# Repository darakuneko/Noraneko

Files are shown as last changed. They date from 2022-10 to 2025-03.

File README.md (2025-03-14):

# Noraneko Project
Noraneko Project is an open source keyboard project.

## License
Coffee License [en](/LICENSE) / [ja](/LICENSE_JA)

☕️☕️☕️ Donation ☕️☕️☕️   
[Amazon](https://www.amazon.co.jp/hz/wishlist/ls/66VQJTRHISQT) or [Ko-fi](https://ko-fi.com/darakuneko)  

If you did sell or modify them, please let us know.

As the author, I would be very happy if you would do so.

Also if you have any questions, [please contact me](https://twitter.com/daraku__neko).

## Why is it not wired?
I want to see a variety of wires on one keyboard.

It makes for good wiring practice.

If wired, pull request kicad_pcb file under each data.

example: [wired](./noraneko42c/v1.0/pcb/wired/)  
/{keyboard}/.../pcb/wired/{username}/ 

### Wiring Engineer
[blackout](https://github.com/blackout157w) - [Noraneko52R v1.0](https://github.com/darakuneko/Noraneko/tree/main/noraneko52r/v1.0/pcb/wired/blackout)

## About Plate Data
I only have data for elecrow.

If you have created data for other stores, please make a pull request.

/{keyboard}/.../plate/{shop}/

## About Noraneko Symbol & Footprint
base on geek-rabb1t's Symbol & Footprint.

https://github.com/geek-rabb1t/keyboard_footprint

## Noraneko42C
Column Staggered Layout Keyboard.
Noraneko42C_IMG_1
Noraneko42C_IMG_2

## Noraneko52R
Row Staggered Layout Keyboard.
PB110431

## Noraneko42W
Willow Layout Keyboard.


# Noraneko42L
Lotus Layout Keyboard.


# Noraneko42GR
Grin Layout Keyboard.


# Noraneko42A
Alice Layout Keyboard.


# Noraneko42SGR
Sagittarius Layout Keyboard.


# Noraneko42UZU  
Uzu Layout Keyboard.


# Noraneko42O
Ortholinear Layout Keyboard.


# Noraneko43TS
Symmetric staggered Layout (Treadstone Layout) keyboard.


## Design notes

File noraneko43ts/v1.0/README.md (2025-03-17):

# Noraneko43TS


Noraneko43TS is 43key Symmetric staggered Layout (Treadstone Layout) keyboard.

## Parts  

Top acrylic plate --- 1 pc  
Middle acrylic plate --- 1 pc   
Main FR4 plate --- 1 pc   
Bottom acrylic plate --- 1 pc   
M2 spacer 3mm --- 6 pcs  
M2 screw 3mm --- 12 pcs  (Screw heads should be 2 mm or less）  
M2 washer --- 6 pcs  
RP2040-Zero --- 1 pc   
1N4148W --- 43 pcs  
SK6812MINI-E --- 43 pcs  
WS2812B --- 6 pcs  
MX key switch --- 43 pcs    
MX keycap    
Bumpon --- Any quantity 

## Firmware

[Firmware](https://github.com/darakuneko/Noraneko/raw/main/noraneko43ts/v1.0/firmware/noraneko43ts_vial.uf2)  
Check if the firmware can write to RP2040-Zero.  
Download the firmware.   
Connect while holding down the Boot button.  
RPI-RP2 will appear.  
Copy the downloaded firmware to RPI-RP2.  
Make sure that Noraneko43TS is connected to your PC.    
[Vial Support](https://get.vial.today/)  

## Soldering



unnamed

RP2040-Zero(SMD), Solder BSS138, Resistors, diodes, LEDs, and sockets.　  
Be careful of the direction of soldering.  
But Resistors has no polarity.

## Build


Take the bottom acrylic paper.   
Install spacers, screws, and Bumpon on bottom plate and main plate.

## Completed!!


Take the top & middle acrylic paper.  
Put on the switches and keycaps and you're done!!

## Vial 
https://get.vial.today/  
This firmware is Vial-compatible, allowing GUI-based changes to keymaps and settings.  

Web version  
https://vial.rocks/  
App version  
https://get.vial.today/download/

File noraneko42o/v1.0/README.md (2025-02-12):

# Noraneko42O  


The Noraneko42O is 42key Ortholinear Layout keyboard.  

## Parts  

Top acrylic plate --- 1 pc  
Middle acrylic plate --- 1 pc   
Main FR4 plate --- 1 pc  
Bottom1 acrylic plate --- 1 pc    
Bottom2 acrylic plate --- 1 pc  
M2 washer --- 8 pcs  
M2 spacer 3mm --- 8 pcs  
M2 screw 3.5mm --- 16 pcs (Screw heads should be 2 mm or less）  
RP2040-Zero --- 1 pc   
EC12 Rotary Encoder --- 1 pc   
1N4148W --- 42 pcs   
SK6812MINI-E --- 42 pcs  
WS2812B --- 5 pcs  
MX key switch --- 42 pcs   
MX keycap  --- 42 pcs  
Bumpon --- Any quantity 

## Firmware
    
[Firmware](https://github.com/darakuneko/Noraneko/raw/main/noraneko42o/v1.0/firmware/noraneko42o_vial.uf2)    
Check if the firmware can write to RP2040-Zero.  
Download the firmware.   
Connect while holding down the Boot button.  
RPI-RP2 will appear.  
Copy the downloaded firmware to RPI-RP2.  
Make sure that Noraneko42O is connected to your PC.   
[Vial Support](https://get.vial.today/)  

## Soldering





RP2040-Zero, Encoder, diodes, LEDs and sockets.　  
Be careful of the direction of soldering.  

## Build


Take the bottom acrylic paper.    
Install washer, spacers, screws, and Bumpon on bottom plate and main plate.    

## Completed!!


Take the top & middle acrylic paper.  
Put on the switches and keycaps and you're done!!

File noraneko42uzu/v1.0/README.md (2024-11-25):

# Noraneko42UZU  


The Noraneko42UZU is 42key UZU Layout keyboard.  

## Parts  

Top acrylic plate --- 1 pc  
Middle acrylic plate --- 1 pc   
Main FR4 plate --- 1 pc  
Bottom1 acrylic plate --- 1 pc    
Bottom2 acrylic plate --- 1 pc  
M2 spacer 3mm --- 8 pcs  
M2 screw 3mm --- 16 pcs  (Screw heads should be 2 mm or less）  
RP2040-Zero --- 1 pc   
EC12 Rotary Encoder --- 1 pc   
1N4148W --- 42 pcs   
SK6812MINI-E --- 42 pcs  
WS2812B --- 7 pcs  
MX key switch --- 42 pcs   
MX keycap  --- 42 pcs  
Bumpon --- Any quantity 

## Firmware
    
[Firmware](https://github.com/darakuneko/Noraneko/raw/main/noraneko42uzu/v1.0/firmware/noraneko42uzu_vial.uf2)    
Check if the firmware can write to RP2040-Zero.  
Download the firmware.   
Connect while holding down the Boot button.  
RPI-RP2 will appear.  
Copy the downloaded firmware to RPI-RP2.  
Make sure that Noraneko42UZU is connected to your PC.   
[Vial Support](https://get.vial.today/)  

## Soldering





RP2040-Zero, Encoder, diodes, LEDs and sockets.　  
Be careful of the direction of soldering.  

## Build


Take the bottom acrylic paper.    
Install washer, spacers, screws, and Bumpon on bottom plate and main plate.    

## Completed!!


Take the top & middle acrylic paper.  
Put on the switches and keycaps and you're done!!

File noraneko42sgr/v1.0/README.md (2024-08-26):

# Noraneko42SGR  

keyboard-layout

The Noraneko42SGR is 42key Sagittarius Layout keyboard.  

## Parts  

Top acrylic plate --- 1 pc  
Middle acrylic plate --- 1 pc   
Main FR4 plate --- 1 pc  
Bottom1 acrylic plate --- 1 pc    
Bottom2 acrylic plate --- 1 pc  
M2 spacer 3mm --- 7 pcs  
M2 screw 3.5mm --- 14 pcs  (Screw heads should be 2 mm or less）  
RP2040-Zero --- 1 pc   
1N4148W --- 42 pcs   
SK6812MINI-E --- 42 pcs  
WS2812B --- 7 pcs  
MX key switch --- 42 pcs   
MX keycap    
https://booth.pximg.net/3a4d6577-cfc5-4ca5-92b6-a2b233b974d5/i/6043317/fea123fa-a97e-4534-b815-77e4f652dba9.png   
Bumpon --- Any quantity 

## Firmware
    
[Firmware](https://github.com/darakuneko/Noraneko/raw/main/noraneko42sgr/v1.0/firmware/noraneko42sgr_vial.uf2)    
Check if the firmware can write to RP2040-Zero.  
Download the firmware.   
Connect while holding down the Boot button.  
RPI-RP2 will appear.  
Copy the downloaded firmware to RPI-RP2.  
Make sure that Noraneko42SGR is connected to your PC.   
[Vial Support](https://get.vial.today/)  

## Soldering




RP2040-Zero, diodes, LEDs and sockets.　  
Be careful of the direction of soldering.  

## Build



Take the bottom acrylic paper.    
Install washer, spacers, screws, and Bumpon on bottom plate and main plate.    

## Completed!!


Take the top & middle acrylic paper.  
Put on the switches and keycaps and you're done!!

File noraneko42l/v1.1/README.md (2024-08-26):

# Noraneko42L



Noraneko42L is 42key Lotus Layout keyboard.  

## Parts  

Top acrylic plate --- 1 pc  
Middle acrylic plate --- 1 pc   
Main FR4 plate --- 1 pc   
Bottom acrylic plate --- 1 pc   
M2 spacer 3mm --- 9 pcs  
M2 screw 3mm --- 18 pcs  (Screw heads should be 2 mm or less）  
RP2040-Zero --- 1 pc   
1N4148W --- 42 pcs  
SK6812MINI-E --- 45 pcs  
WS2812B --- 8 pcs  
MX key switch --- 42 pcs    
MX keycap   --- 42 pcs (1U)   
Bumpon --- Any quantity 

## Firmware

[Firmware](https://github.com/darakuneko/Noraneko/raw/main/noraneko42l/v1.1/firmware/noraneko42l_vial.uf2)   
Check if the firmware can write to RP2040-Zero.  
Download the firmware.   
Connect while holding down the Boot button.  
RPI-RP2 will appear.  
Copy the downloaded firmware to RPI-RP2.  
Make sure that Noraneko42L is connected to your PC.    
[Vial Support](https://get.vial.today/)  

### Feature
CAPS WORD  
https://github.com/qmk/qmk_firmware/blob/master/docs/feature_caps_word.md   

## Soldering



unnamed

RP2040-Zero(SMD), diodes, LEDs, and sockets.　  
Be careful of the direction of soldering.  
But Resistors has no polarity.

## Build


Take the bottom acrylic paper.   
Install spacers, screws, and Bumpon on bottom plate and main plate.   

If you are concerned about LED flicker caused by acrylic.  
https://twitter.com/daraku__neko/status/1652335060878753798

## Completed!!


Take the top & middle acrylic paper.  
Put on the switches and keycaps and you're done!!

## Vial 
https://get.vial.today/  
This firmware is Vial-compatible, allowing GUI-based changes to keymaps and settings.  

Web version  
https://vial.rocks/  
App version  
https://get.vial.today/download/

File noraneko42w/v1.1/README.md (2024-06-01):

# Noraneko42W

77f7c019-44f0-4f18-8f08-11a2cd835d37

Noraneko42W is 42key Willow Layout keyboard.  

## Parts  

Top acrylic plate --- 1 pc  
Middle acrylic plate --- 1 pc   
Main FR4 plate --- 1 pc   
Bottom acrylic plate --- 1 pc   
M2 spacer 3mm --- 9 pcs  
M2 screw 3mm --- 18 pcs  (Screw heads should be 2 mm or less）  
RP2040-Zero --- 1 pc   
1N4148W --- 42 pcs  
SK6812MINI-E --- 45 pcs  
WS2812B --- 12 pcs  
MX key switch --- 42 pcs    
MX keycap   --- 42 pcs (1U)   
Bumpon --- Any quantity 

## Firmware

[Firmware](https://github.com/darakuneko/Noraneko/raw/main/noraneko42w/v1.0/firmware/noraneko42w_vial.uf2)  
Check if the firmware can write to RP2040-Zero.  
Download the firmware.   
Connect while holding down the Boot button.  
RPI-RP2 will appear.  
Copy the downloaded firmware to RPI-RP2.  
Make sure that Noraneko42W is connected to your PC.    
[Vial Support](https://get.vial.today/)  

## Soldering



unnamed

RP2040-Zero(SMD), Solder BSS138, Resistors, diodes, LEDs, and sockets.　  
Be careful of the direction of soldering.  
But Resistors has no polarity.

## Build
77f7c019-44f0-4f18-8f08-11a2cd835d37

Take the bottom acrylic paper.   
Install spacers, screws, and Bumpon on bottom plate and main plate.

If you are concerned about LED flicker caused by acrylic.  
https://twitter.com/daraku__neko/status/1652335060878753798

## Completed!!


Take the top & middle acrylic paper.  
Put on the switches and keycaps and you're done!!

## Vial 
https://get.vial.today/  
This firmware is Vial-compatible, allowing GUI-based changes to keymaps and settings.  

Web version  
https://vial.rocks/  
App version  
https://get.vial.today/download/

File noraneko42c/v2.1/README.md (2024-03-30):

# Noraneko42C  
Noraneko42C_IMG_1
Noraneko42C_KeySize

The Noraneko42C is 42key column staggered keyboard.  

## Parts  

Top acrylic plate --- 1 pc  
Middle acrylic plate --- 1 pc   
Main FR4 plate --- 1 pc  
Bottom1 acrylic plate --- 1 pc    
Bottom2 acrylic plate --- 1 pc  
M2 spacer 3mm --- 7 pcs  
M2 screw 3mm --- 14 pcs  (Screw heads should be 2 mm or less）  
RP2040-Zero --- 1 pc   
1N4148W --- 42 pcs   
SK6812MINI-E --- 47 pcs  
WS2812B --- 6 pcs  
MX key switch --- 42 pcs   
MX keycap 1U --- 38 pcs  
MX keycap 1.25U --- 4 pcs  
Bumpon --- Any quantity 

## Firmware

Firmware
[v2.1](https://github.com/darakuneko/Noraneko/raw/main/noraneko42c/v2.1/firmware/noraneko42c_vial.uf2)  
Old Firmware
[v2.0](https://github.com/darakuneko/Noraneko/raw/main/noraneko42c/v2.0/firmware/noraneko42c_vial.uf2)  
Check if the firmware can write to RP2040-Zero.  
Download the firmware.   
Connect while holding down the Boot button.  
RPI-RP2 will appear.  
Copy the downloaded firmware to RPI-RP2.  
Make sure that Noraneko42C is connected to your PC.    
[Vial Support](https://get.vial.today/)  

### Feature
CAPS WORD  
https://github.com/qmk/qmk_firmware/blob/master/docs/feature_caps_word.md   

## Soldering



unnamed

RP2040-Zero(SMD),diodes, LEDs, and sockets.  
Be careful of the direction of soldering.  
But Resistors has no polarity.

## Build
Take the bottom acrylic paper.
Install spacers, screws, and Bumpon on bottom plate and main plate.
Use black masking tape to hide the LEDs.

If you are concerned about LED flicker caused by acrylic.  
https://twitter.com/daraku__neko/status/1652335060878753798

## Completed!!



Take the top & middle acrylic paper.  
Put on the switches and keycaps and you're done!!

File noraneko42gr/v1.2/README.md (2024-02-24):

# Noraneko42GR  

keyboard-layout

The Noraneko42GR is 42key GRIN Layout keyboard.  

## Parts  

Top acrylic plate --- 1 pc  
Middle acrylic plate --- 1 pc   
Main FR4 plate --- 1 pc  
Bottom1 acrylic plate --- 1 pc    
Bottom2 acrylic plate --- 1 pc  
M2 spacer 3mm or 3.5mm --- 7 pcs  
M2 washer --- 7 pcs  (Some plates require approx. 5 mm in diameter）  
M2 screw 3mm --- 14 pcs  (Screw heads should be 2 mm or less）  
RP2040-Zero --- 1 pc   
Conthrough --- 23 pin (MAC8 XB-3 height at least 3 mm)    
1N4148W --- 42 pcs   
SK6812MINI-E --- 42 pcs  
WS2812B --- 6 pcs  
MX key switch --- 42 pcs   
Stabilizers 2U --- 2 pcs    
MX keycap    
https://booth.pximg.net/3a4d6577-cfc5-4ca5-92b6-a2b233b974d5/i/4311339/b372f2f2-1520-4431-a8cc-eac1ec2c977d.png   
Bumpon --- Any quantity 

## Firmware
    
[Firmware](https://github.com/darakuneko/Noraneko/raw/main/noraneko42gr/v1.1/firmware/noraneko42gr_vial.uf2)    
Check if the firmware can write to RP2040-Zero.  
Download the firmware. (Firmware prior to v1.1 is on a separate pagel)     
Connect while holding down the Boot button.  
RPI-RP2 will appear.  
Copy the downloaded firmware to RPI-RP2.  
Make sure that Noraneko42GR is connected to your PC.   
[Vial Support](https://get.vial.today/)  

## Soldering






RP2040-Zero, diodes, LEDs, and sockets.　  
Be careful of the direction of soldering.  
But Resistors has no polarity.

## Build
Take the bottom acrylic paper.    
Install spacers, screws, washer and Bumpon on bottom plate and main plate.    


## Completed!!


Take the top & middle acrylic paper.  
Put on the switches and keycaps and you're done!!

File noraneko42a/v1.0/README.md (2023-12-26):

# Noraneko42A  

keyboard-layout

The Noraneko42A is 42key Alice Layout keyboard.  

## Parts  

Top acrylic plate --- 1 pc  
Middle acrylic plate --- 1 pc   
Main FR4 plate --- 1 pc  
Bottom1 acrylic plate --- 1 pc    
Bottom2 acrylic plate --- 1 pc  
M2 washer --- 7 pcs  
M2 spacer 3mm --- 7 pcs  
M2 screw 3.5mm --- 14 pcs  (Screw heads should be 2 mm or less）  
RP2040-Zero --- 1 pc   
1N4148W --- 42 pcs   
SK6812MINI-E --- 42 pcs  
WS2812B --- 8 pcs  
MX key switch --- 42 pcs   
Stabilizers 2U --- 2 pcs    
MX keycap    
https://booth.pximg.net/3a4d6577-cfc5-4ca5-92b6-a2b233b974d5/i/5374158/5d14389b-c7e3-49fb-a8d4-9945c7a1167a.png   
Bumpon --- Any quantity 

## Firmware
    
[Firmware](https://github.com/darakuneko/Noraneko/raw/main/noraneko42a/v1.0/firmware/noraneko42a_vial.uf2)    
Check if the firmware can write to RP2040-Zero.  
Download the firmware.   
Connect while holding down the Boot button.  
RPI-RP2 will appear.  
Copy the downloaded firmware to RPI-RP2.  
Make sure that Noraneko42A is connected to your PC.   
[Vial Support](https://get.vial.today/)  

## Soldering




RP2040-Zero, diodes, LEDs and sockets.　  
Be careful of the direction of soldering.  

## Build


Take the bottom acrylic paper.    
Install washer, spacers, screws, and Bumpon on bottom plate and main plate.    

## Completed!!


Take the top & middle acrylic paper.  
Put on the switches and keycaps and you're done!!

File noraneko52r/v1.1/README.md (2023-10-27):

# Noraneko52R  
PB110430


Noraneko52R is 52key row staggered keyboard.  

## Parts  

Top acrylic plate --- 1 pc  
Middle acrylic plate --- 1 pc   
Main FR4 plate --- 1 pc   
Bottom1 acrylic plate --- 1 pc   
Bottom2 acrylic plate --- 1 pc   
M2 spacer 3mm --- 7 pcs  
M2 screw 3mm --- 14 pcs  (Screw heads should be 2 mm or less）  
RP2040-Zero --- 1 pc  
Pin header 9pin --- 2 pcs   
Pin header 5pin --- 1 pc  
1N4148W --- 52 pcs  
SK6812MINI-E --- 52 pcs  
WS2812B --- 13 pcs  
BSS138 --- 1 pc  
Resistor 1K Ohm 1/4 Watt PTH --- 2 pcs   
If it does not glow, change the type of resistor. ([reference](https://25keys.com/2022/05/28/rp2040_sk6812mini/))   

MX key switch --- 52 pcs  
Stabilizers 2U --- 2 pcs (GMK Screw-in Stabilizers are recommended)   
MX keycap    
https://booth.pximg.net/3a4d6577-cfc5-4ca5-92b6-a2b233b974d5/i/4311339/b372f2f2-1520-4431-a8cc-eac1ec2c977d.png   
Bumpon --- Any quantity 

## Firmware

[Firmware](https://github.com/darakuneko/Noraneko/raw/main/noraneko52r/v1.0/firmware/noraneko52r_vial.uf2)  
Check if the firmware can write to RP2040-Zero.  
Download the firmware.   
Connect while holding down the Boot button.  
RPI-RP2 will appear.  
Copy the downloaded firmware to RPI-RP2.  
Make sure that Noraneko52R is connected to your PC.    
[Vial Support](https://get.vial.today/)  

### Feature
CAPS WORD  
https://github.com/qmk/qmk_firmware/blob/master/docs/feature_caps_word.md   

## Soldering






Solder BSS138, Resistors, diodes, LEDs, and sockets.　  
Be careful of the direction of soldering.  
But Resistors has no polarity.

RP2040-Zero

For direct soldering using pin headers, see [here](https://kbdbuild.vercel.app/blog/yamada_pro_micro).  
This is doing this with ProMicro, but it is the same with RP2040-Zero.   
Be careful of the direction of soldering.  

## Build


the screw part's height of the stabilizer should be 3mm or less.   
GMK Screw-in Stabilizers are recommended.   




Take the bottom1 & bottom2 acrylic paper.   
Install spacers, screws, and Bumpon on bottom plate and main plate.

If you are concerned about LED flicker caused by acrylic.  
https://twitter.com/daraku__neko/status/1652335060878753798

## Completed!!
PB110430

Take the top & middle acrylic paper.  
Put on the switches and keycaps and you're done!!

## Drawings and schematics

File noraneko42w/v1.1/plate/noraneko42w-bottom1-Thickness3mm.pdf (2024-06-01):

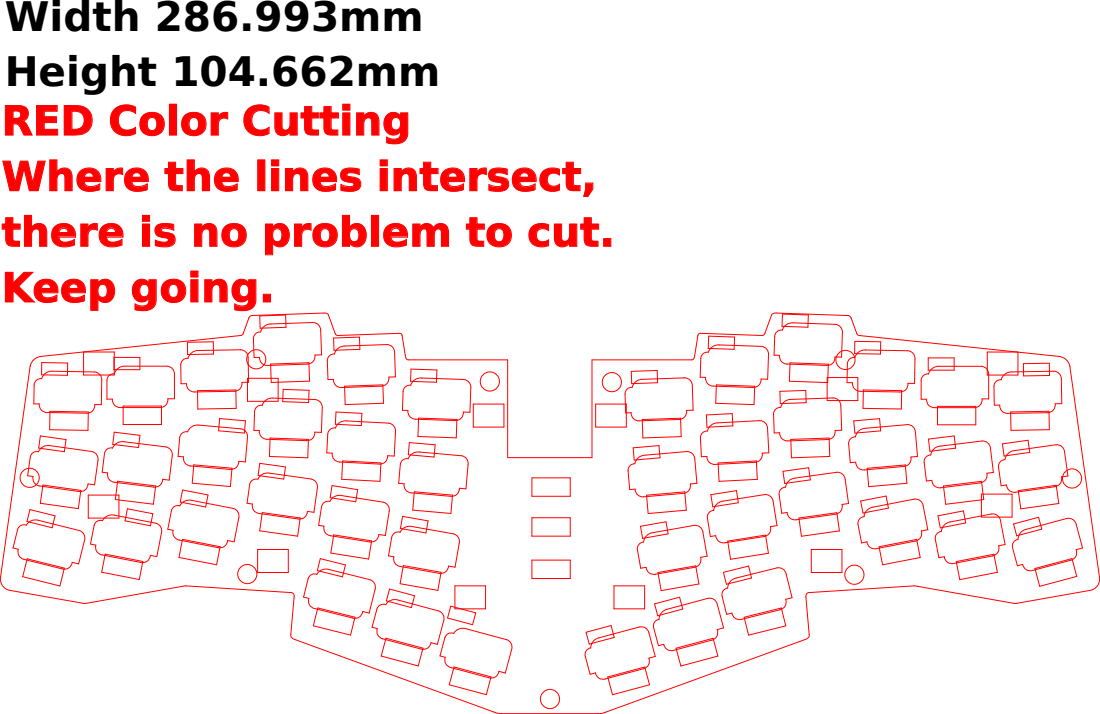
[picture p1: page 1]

Width 286.993mm
Height 104.662mm
RED Color Cutting
Where the lines intersect,
there is no problem to cut.
Keep going.

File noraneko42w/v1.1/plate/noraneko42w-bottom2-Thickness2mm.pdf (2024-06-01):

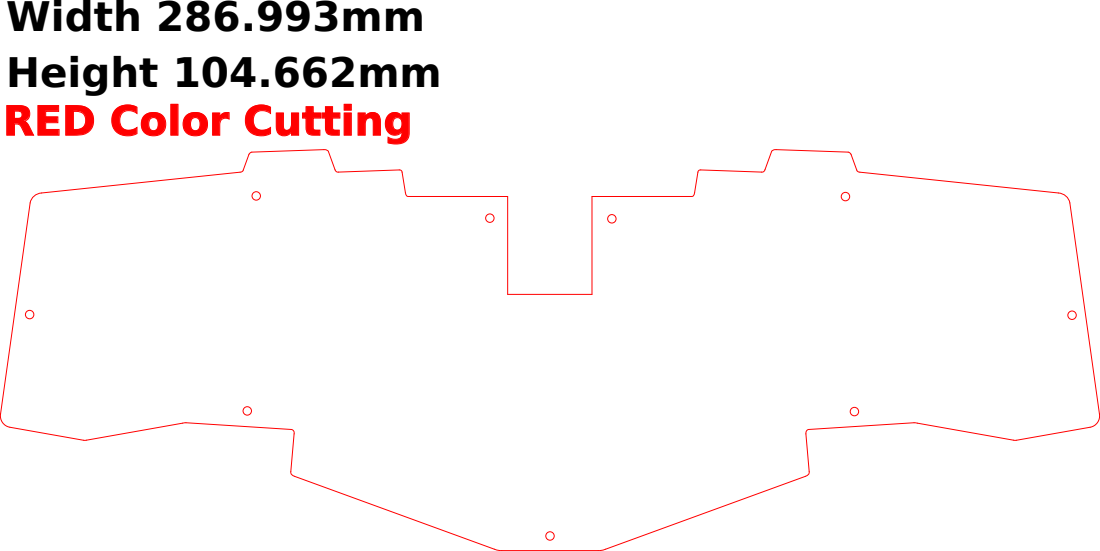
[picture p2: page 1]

Width 286.993mm
Height 104.662mm
RED Color Cutting

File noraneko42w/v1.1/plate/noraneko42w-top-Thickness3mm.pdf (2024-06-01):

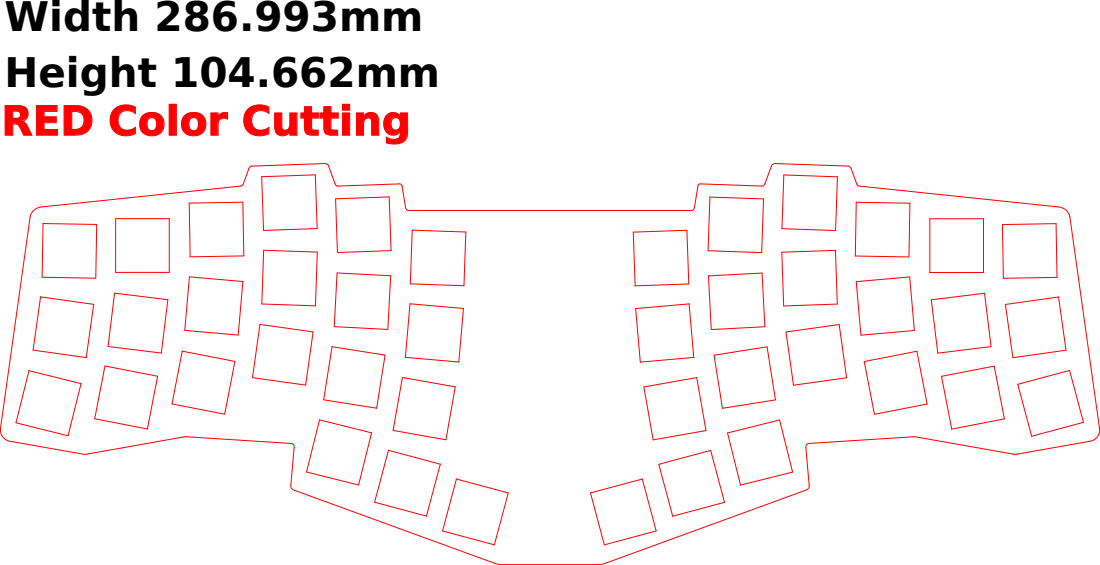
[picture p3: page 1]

Width 286.993mm
Height 104.662mm
RED Color Cutting

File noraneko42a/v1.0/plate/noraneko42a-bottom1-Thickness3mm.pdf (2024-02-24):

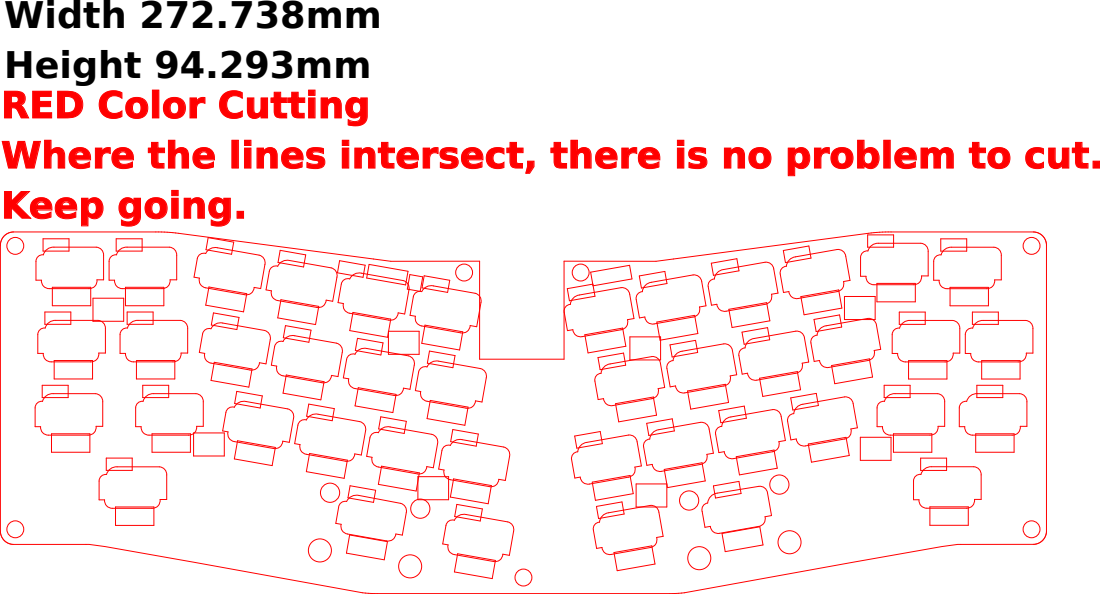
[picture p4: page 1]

Width 272.738mm
Height 94.293mm
RED Color Cutting
Where the lines intersect, there is no problem to cut.
Keep going.

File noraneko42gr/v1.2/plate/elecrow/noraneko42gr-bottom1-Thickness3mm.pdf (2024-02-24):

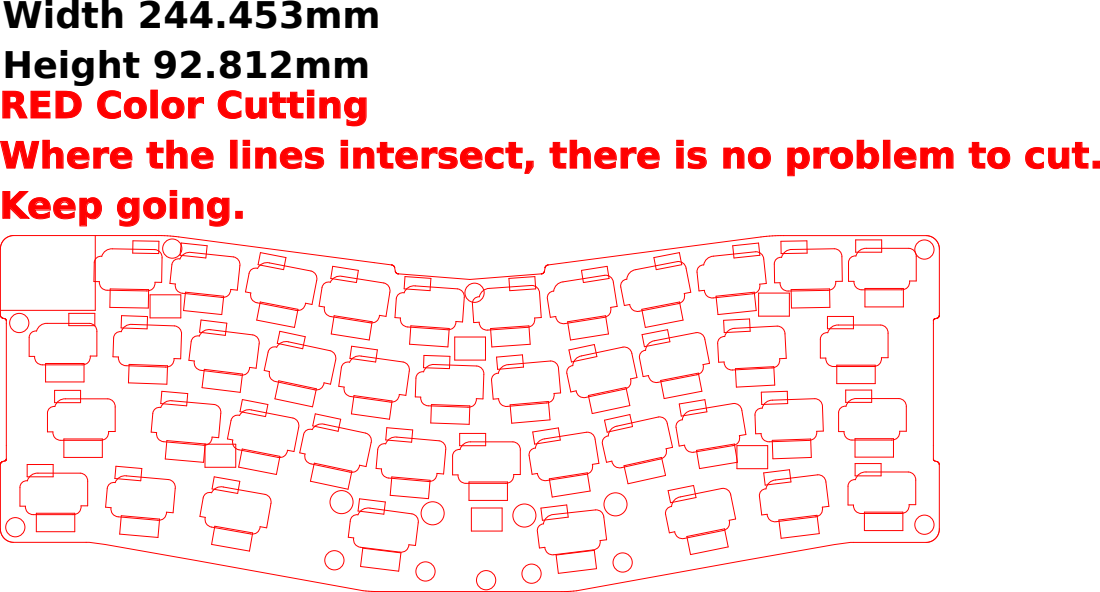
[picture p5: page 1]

Width 244.453mm
Height 92.812mm
RED Color Cutting
Where the lines intersect, there is no problem to cut.
Keep going.

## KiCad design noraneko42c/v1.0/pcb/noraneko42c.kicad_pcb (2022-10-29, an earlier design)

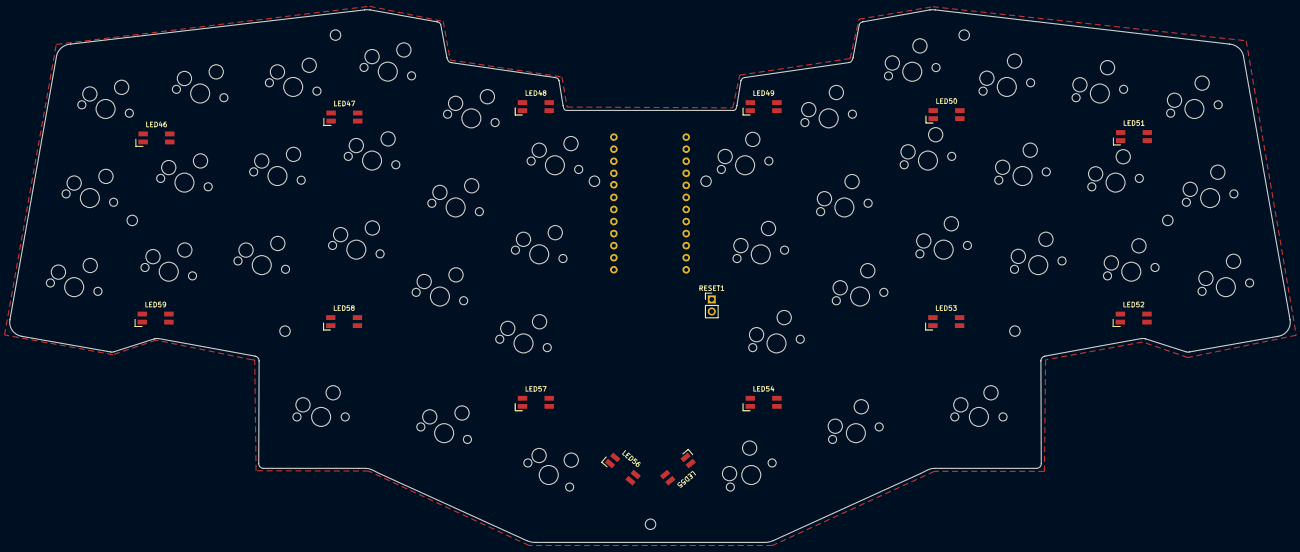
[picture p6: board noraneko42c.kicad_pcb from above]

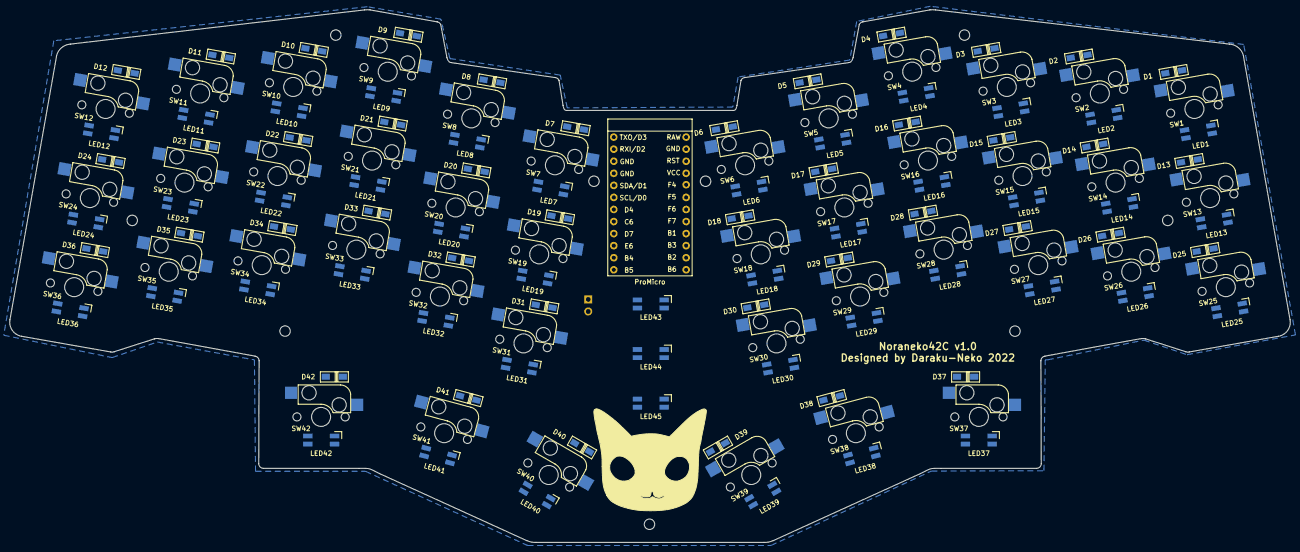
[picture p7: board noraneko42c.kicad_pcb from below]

Board: 2 copper layers, 269.7 x 112.2 mm, 145 parts (88 on the bottom side), 120 nets, no tracks yet.

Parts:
D1, D2, D3, D4, D5, D6, D7, D8, D9, D10, D11, D12, D13, D14, D15, D16, D17, D18, D19, D20, D21, D22, D23, D24, D25, D26, D27, D28, D29, D30, D31, D32, D33, D34, D35, D36, D37, D38, D39, D40, D41, D42: D; 1N4148W
LED1, LED2, LED3, LED4, LED5, LED6, LED7, LED8, LED9, LED10, LED11, LED12, LED13, LED14, LED15, LED16, LED17, LED18, LED19, LED20, LED21, LED22, LED23, LED24, LED25, LED26, LED27, LED28, LED29, LED30, LED31, LED32, LED33, LED34, LED35, LED36, LED37, LED38, LED39, LED40, LED41, LED42, LED43, LED44, LED45, LED46, LED47, LED48, LED49, LED50, LED51, LED52, LED53, LED54, LED55, LED56, LED57, LED58, LED59: SK6812MINI-E
RESET1: SW_Push; PinHeader_1x02_P2.54mm_Vertical
SW1, SW2, SW3, SW4, SW5, SW6, SW7, SW8, SW9, SW10, SW11, SW12, SW13, SW14, SW15, SW16, SW17, SW18, SW19, SW20, SW21, SW22, SW23, SW24, SW25, SW26, SW27, SW28, SW29, SW30, SW31, SW32, SW33, SW34, SW35, SW36, SW37, SW38, SW39, SW40, SW41, SW42: SW_Push; MX_Socket
U1: ProMicro; Pro_Micro

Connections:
COL0: SW1.1, SW13.1, SW25.1, SW37.1, U1.20 (A3/F4)
COL1: SW2.1, SW14.1, SW26.1, SW38.1, U1.19 (A2/F5)
COL2: SW3.1, SW15.1, SW27.1, SW39.1, U1.18 (A1/F6)
COL3: SW4.1, SW16.1, SW28.1, SW40.1, U1.17 (A0/F7)
COL4: SW5.1, SW17.1, SW29.1, SW41.1, U1.16 (B1)
COL5: SW6.1, SW18.1, SW30.1, SW42.1, U1.15 (B3)
COL6: SW7.1, SW19.1, SW31.1, U1.14 (B2)
COL7: SW8.1, SW20.1, SW32.1, U1.13 (B6)
COL8: SW9.1, SW21.1, SW33.1, U1.12 (B5)
COL9: SW10.1, SW22.1, SW34.1, U1.11 (B4)
COL10: SW11.1, SW23.1, SW35.1, U1.10 (E6)
COL11: SW12.1, SW24.1, SW36.1, U1.9 (D7)
GND: LED1.3 (VSS), LED2.3 (VSS), LED3.3 (VSS), LED4.3 (VSS), LED5.3 (VSS), LED6.3 (VSS), LED7.3 (VSS), LED8.3 (VSS), LED9.3 (VSS), LED10.3 (VSS), LED11.3 (VSS), LED12.3 (VSS), LED13.3 (VSS), LED14.3 (VSS), LED15.3 (VSS), LED16.3 (VSS), LED17.3 (VSS), LED18.3 (VSS), LED19.3 (VSS), LED20.3 (VSS), LED21.3 (VSS), LED22.3 (VSS), LED23.3 (VSS), LED24.3 (VSS), LED25.3 (VSS), LED26.3 (VSS), LED27.3 (VSS), LED28.3 (VSS), LED29.3 (VSS), LED30.3 (VSS), LED31.3 (VSS), LED32.3 (VSS), LED33.3 (VSS), LED34.3 (VSS), LED35.3 (VSS), LED36.3 (VSS), LED37.3 (VSS), LED38.3 (VSS), LED39.3 (VSS), LED40.3 (VSS), LED41.3 (VSS), LED42.3 (VSS), LED43.3 (VSS), LED44.3 (VSS), LED45.3 (VSS), LED46.3 (VSS), LED47.3 (VSS), LED48.3 (VSS), LED49.3 (VSS), LED50.3 (VSS), LED51.3 (VSS), LED52.3 (VSS), LED53.3 (VSS), LED54.3 (VSS), LED55.3 (VSS), LED56.3 (VSS), LED57.3 (VSS), LED58.3 (VSS), LED59.3 (VSS), RESET1.2, U1.3 (GND), U1.4 (GND), U1.23 (GND)
LED: LED1.4 (DIN), U1.1 (TX0/D3)
unnamed: D1.2 (A), SW1.2
unnamed: D2.2 (A), SW2.2
unnamed: D3.2 (A), SW3.2
unnamed: D4.2 (A), SW4.2
unnamed: D5.2 (A), SW5.2
unnamed: D6.2 (A), SW6.2
unnamed: D7.2 (A), SW7.2
unnamed: D8.2 (A), SW8.2
unnamed: D9.2 (A), SW9.2
unnamed: D10.2 (A), SW10.2
unnamed: D11.2 (A), SW11.2
unnamed: D12.2 (A), SW12.2
unnamed: D13.2 (A), SW13.2
unnamed: D14.2 (A), SW14.2
unnamed: D15.2 (A), SW15.2
unnamed: D16.2 (A), SW16.2
unnamed: D17.2 (A), SW17.2
unnamed: D18.2 (A), SW18.2
unnamed: D19.2 (A), SW19.2
unnamed: D20.2 (A), SW20.2
unnamed: D21.2 (A), SW21.2
unnamed: D22.2 (A), SW22.2
unnamed: D23.2 (A), SW23.2
unnamed: D24.2 (A), SW24.2
unnamed: D25.2 (A), SW25.2
unnamed: D26.2 (A), SW26.2
unnamed: D27.2 (A), SW27.2
unnamed: D28.2 (A), SW28.2
unnamed: D29.2 (A), SW29.2
unnamed: D30.2 (A), SW30.2
unnamed: D31.2 (A), SW31.2
unnamed: D32.2 (A), SW32.2
unnamed: D33.2 (A), SW33.2
unnamed: D34.2 (A), SW34.2
unnamed: D35.2 (A), SW35.2
unnamed: D36.2 (A), SW36.2
unnamed: D37.2 (A), SW37.2
unnamed: D38.2 (A), SW38.2
unnamed: D39.2 (A), SW39.2
unnamed: D40.2 (A), SW40.2
unnamed: D41.2 (A), SW41.2
unnamed: D42.2 (A), SW42.2
unnamed: LED1.2 (DOUT), LED2.4 (DIN)
unnamed: LED2.2 (DOUT), LED3.4 (DIN)
unnamed: LED3.2 (DOUT), LED4.4 (DIN)
unnamed: LED4.2 (DOUT), LED5.4 (DIN)
unnamed: LED5.2 (DOUT), LED6.4 (DIN)
unnamed: LED6.2 (DOUT), LED7.4 (DIN)
unnamed: LED7.2 (DOUT), LED8.4 (DIN)
unnamed: LED8.2 (DOUT), LED9.4 (DIN)
unnamed: LED10.2 (DOUT), LED11.4 (DIN)
unnamed: LED9.2 (DOUT), LED10.4 (DIN)
unnamed: LED11.2 (DOUT), LED12.4 (DIN)
unnamed: LED12.2 (DOUT), LED13.4 (DIN)
unnamed: LED13.2 (DOUT), LED14.4 (DIN)
unnamed: LED14.2 (DOUT), LED15.4 (DIN)
unnamed: LED15.2 (DOUT), LED16.4 (DIN)
unnamed: LED16.2 (DOUT), LED17.4 (DIN)
unnamed: LED17.2 (DOUT), LED18.4 (DIN)
unnamed: LED18.2 (DOUT), LED19.4 (DIN)
unnamed: LED19.2 (DOUT), LED20.4 (DIN)
unnamed: LED20.2 (DOUT), LED21.4 (DIN)
unnamed: LED21.2 (DOUT), LED22.4 (DIN)
unnamed: LED22.2 (DOUT), LED23.4 (DIN)
unnamed: LED23.2 (DOUT), LED24.4 (DIN)
unnamed: LED24.2 (DOUT), LED25.4 (DIN)
unnamed: LED25.2 (DOUT), LED26.4 (DIN)
unnamed: LED26.2 (DOUT), LED27.4 (DIN)
unnamed: LED27.2 (DOUT), LED28.4 (DIN)
unnamed: LED28.2 (DOUT), LED29.4 (DIN)
unnamed: LED29.2 (DOUT), LED30.4 (DIN)
unnamed: LED30.2 (DOUT), LED31.4 (DIN)
unnamed: LED31.2 (DOUT), LED32.4 (DIN)
unnamed: LED32.2 (DOUT), LED33.4 (DIN)
unnamed: LED33.2 (DOUT), LED34.4 (DIN)
unnamed: LED34.2 (DOUT), LED35.4 (DIN)
unnamed: LED35.2 (DOUT), LED36.4 (DIN)
unnamed: LED36.2 (DOUT), LED37.4 (DIN)
unnamed: LED37.2 (DOUT), LED38.4 (DIN)
unnamed: LED38.2 (DOUT), LED39.4 (DIN)
unnamed: LED39.2 (DOUT), LED40.4 (DIN)
unnamed: LED40.2 (DOUT), LED41.4 (DIN)
unnamed: LED41.2 (DOUT), LED42.4 (DIN)
unnamed: LED42.2 (DOUT), LED43.4 (DIN)
unnamed: LED43.2 (DOUT), LED44.4 (DIN)
unnamed: LED44.2 (DOUT), LED45.4 (DIN)
unnamed: LED45.2 (DOUT), LED46.4 (DIN)
unnamed: LED46.2 (DOUT), LED47.4 (DIN)
unnamed: LED47.2 (DOUT), LED48.4 (DIN)
unnamed: LED48.2 (DOUT), LED49.4 (DIN)
unnamed: LED49.2 (DOUT), LED50.4 (DIN)
unnamed: LED50.2 (DOUT), LED51.4 (DIN)
unnamed: LED51.2 (DOUT), LED52.4 (DIN)
unnamed: LED52.2 (DOUT), LED53.4 (DIN)
unnamed: LED53.2 (DOUT), LED54.4 (DIN)
unnamed: LED54.2 (DOUT), LED55.4 (DIN)
unnamed: LED55.2 (DOUT), LED56.4 (DIN)
unnamed: LED56.2 (DOUT), LED57.4 (DIN)
unnamed: LED57.2 (DOUT), LED58.4 (DIN)
unnamed: LED58.2 (DOUT), LED59.4 (DIN)
ROW0: D1.1 (K), D2.1 (K), D3.1 (K), D4.1 (K), D5.1 (K), D6.1 (K), D7.1 (K), D8.1 (K), D9.1 (K), D10.1 (K), D11.1 (K), D12.1 (K), U1.8 (C6)
ROW1: D13.1 (K), D14.1 (K), D15.1 (K), D16.1 (K), D17.1 (K), D18.1 (K), D19.1 (K), D20.1 (K), D21.1 (K), D22.1 (K), D23.1 (K), D24.1 (K), U1.7 (D4)
ROW2: D25.1 (K), D26.1 (K), D27.1 (K), D28.1 (K), D29.1 (K), D30.1 (K), D31.1 (K), D32.1 (K), D33.1 (K), D34.1 (K), D35.1 (K), D36.1 (K), U1.6 (SCL/D0)
ROW3: D37.1 (K), D38.1 (K), D39.1 (K), D40.1 (K), D41.1 (K), D42.1 (K), U1.5 (SDA/D1)
VCC: LED1.1 (VDD), LED2.1 (VDD), LED3.1 (VDD), LED4.1 (VDD), LED5.1 (VDD), LED6.1 (VDD), LED7.1 (VDD), LED8.1 (VDD), LED9.1 (VDD), LED10.1 (VDD), LED11.1 (VDD), LED12.1 (VDD), LED13.1 (VDD), LED14.1 (VDD), LED15.1 (VDD), LED16.1 (VDD), LED17.1 (VDD), LED18.1 (VDD), LED19.1 (VDD), LED20.1 (VDD), LED21.1 (VDD), LED22.1 (VDD), LED23.1 (VDD), LED24.1 (VDD), LED25.1 (VDD), LED26.1 (VDD), LED27.1 (VDD), LED28.1 (VDD), LED29.1 (VDD), LED30.1 (VDD), LED31.1 (VDD), LED32.1 (VDD), LED33.1 (VDD), LED34.1 (VDD), LED35.1 (VDD), LED36.1 (VDD), LED37.1 (VDD), LED38.1 (VDD), LED39.1 (VDD), LED40.1 (VDD), LED41.1 (VDD), LED42.1 (VDD), LED43.1 (VDD), LED44.1 (VDD), LED45.1 (VDD), LED46.1 (VDD), LED47.1 (VDD), LED48.1 (VDD), LED49.1 (VDD), LED50.1 (VDD), LED51.1 (VDD), LED52.1 (VDD), LED53.1 (VDD), LED54.1 (VDD), LED55.1 (VDD), LED56.1 (VDD), LED57.1 (VDD), LED58.1 (VDD), LED59.1 (VDD), U1.21 (VCC)
reset: RESET1.1, U1.22 (RST)

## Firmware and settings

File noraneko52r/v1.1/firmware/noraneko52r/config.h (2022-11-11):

/*
Copyright 2022 daraku_neko
This program is free software: you can redistribute it and/or modify
it under the terms of the GNU General Public License as published by
the Free Software Foundation, either version 2 of the License, or
(at your option) any later version.
This program is distributed in the hope that it will be useful,
but WITHOUT ANY WARRANTY; without even the implied warranty of
MERCHANTABILITY or FITNESS FOR A PARTICULAR PURPOSE.  See the
GNU General Public License for more details.
You should have received a copy of the GNU General Public License
along with this program.  If not, see <http://www.gnu.org/licenses/>.
*/

#pragma once

#include "config_common.h"

/* USB Device descriptor parameter */
#define VENDOR_ID    0xFEED
#define PRODUCT_ID   0x1527
#define DEVICE_VER   0x0001
#define MANUFACTURER Daraku-Neko
#define PRODUCT      Noraneko52R

#define RGB_DI_PIN GP0
#define RGBLED_NUM 65
#define DRIVER_LED_TOTAL 65
#define RGB_MATRIX_MAXIMUM_BRIGHTNESS 200
#define RGB_MATRIX_CENTER { 112, 32 }
#define RGB_DISABLE_TIMEOUT 120000
#define RGB_DISABLE_WHEN_USB_SUSPENDED true
#define RGB_MATRIX_HUE_STEP 4
#define RGB_MATRIX_SAT_STEP 4
#define RGB_MATRIX_VAL_STEP 4
#define RGB_MATRIX_SPD_STEP 4
#define RGB_MATRIX_KEYPRESSES
#define RGB_MATRIX_FRAMEBUFFER_EFFECTS
#define ENABLE_RGB_MATRIX_ALPHAS_MODS
#define ENABLE_RGB_MATRIX_GRADIENT_UP_DOWN
#define ENABLE_RGB_MATRIX_GRADIENT_LEFT_RIGHT
#define ENABLE_RGB_MATRIX_BREATHING
#define ENABLE_RGB_MATRIX_BAND_SAT
#define ENABLE_RGB_MATRIX_BAND_VAL
#define ENABLE_RGB_MATRIX_BAND_PINWHEEL_SAT
#define ENABLE_RGB_MATRIX_BAND_PINWHEEL_VAL
#define ENABLE_RGB_MATRIX_BAND_SPIRAL_SAT
#define ENABLE_RGB_MATRIX_BAND_SPIRAL_VAL
#define ENABLE_RGB_MATRIX_CYCLE_ALL
#define ENABLE_RGB_MATRIX_CYCLE_LEFT_RIGHT
#define ENABLE_RGB_MATRIX_CYCLE_UP_DOWN
#define ENABLE_RGB_MATRIX_RAINBOW_MOVING_CHEVRON
#define ENABLE_RGB_MATRIX_CYCLE_OUT_IN
#define ENABLE_RGB_MATRIX_CYCLE_OUT_IN_DUAL
#define ENABLE_RGB_MATRIX_CYCLE_PINWHEEL
#define ENABLE_RGB_MATRIX_CYCLE_SPIRAL
#define ENABLE_RGB_MATRIX_DUAL_BEACON
#define ENABLE_RGB_MATRIX_RAINBOW_BEACON
#define ENABLE_RGB_MATRIX_RAINBOW_PINWHEELS
#define ENABLE_RGB_MATRIX_RAINDROPS
#define ENABLE_RGB_MATRIX_JELLYBEAN_RAINDROPS
#define ENABLE_RGB_MATRIX_HUE_BREATHING
#define ENABLE_RGB_MATRIX_HUE_PENDULUM
#define ENABLE_RGB_MATRIX_HUE_WAVE
#define ENABLE_RGB_MATRIX_PIXEL_FRACTAL
#define ENABLE_RGB_MATRIX_PIXEL_FLOW
#define ENABLE_RGB_MATRIX_PIXEL_RAIN
#define ENABLE_RGB_MATRIX_TYPING_HEATMAP
#define ENABLE_RGB_MATRIX_DIGITAL_RAIN
#define ENABLE_RGB_MATRIX_SOLID_REACTIVE_SIMPLE
#define ENABLE_RGB_MATRIX_SOLID_REACTIVE
#define ENABLE_RGB_MATRIX_SOLID_REACTIVE_WIDE
#define ENABLE_RGB_MATRIX_SOLID_REACTIVE_MULTIWIDE
#define ENABLE_RGB_MATRIX_SOLID_REACTIVE_CROSS
#define ENABLE_RGB_MATRIX_SOLID_REACTIVE_MULTICROSS
#define ENABLE_RGB_MATRIX_SOLID_REACTIVE_NEXUS
#define ENABLE_RGB_MATRIX_SOLID_REACTIVE_MULTINEXUS
#define ENABLE_RGB_MATRIX_SPLASH
#define ENABLE_RGB_MATRIX_MULTISPLASH
#define ENABLE_RGB_MATRIX_SOLID_SPLASH
#define ENABLE_RGB_MATRIX_SOLID_MULTISPLASH
#define RGB_MATRIX_STARTUP_MODE RGB_MATRIX_CYCLE_UP_DOWN

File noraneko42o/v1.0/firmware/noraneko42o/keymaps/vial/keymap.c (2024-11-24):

/* SPDX-License-Identifier: GPL-2.0-or-later */

#include QMK_KEYBOARD_H

const uint16_t PROGMEM keymaps[][MATRIX_ROWS][MATRIX_COLS] = {
	[0] = LAYOUT(
		KC_Q, KC_W, KC_E, KC_R, KC_T, KC_Y, KC_U, KC_I, KC_O, KC_P,
		KC_A, KC_S, KC_D, KC_F, KC_G, KC_H, KC_J, KC_K, KC_L, KC_BSLS,
		KC_Z, KC_X, KC_C, KC_V, KC_B, KC_MEDIA_PLAY_PAUSE, KC_N, KC_M, KC_COMM, KC_DOT, KC_SLSH,
		KC_LSFT, MO(2), KC_LGUI, KC_LCTL, KC_LOPT, LT(1, KC_SPC), LT(1, KC_ENT), KC_BSPC, KC_RALT, KC_RCTL, MO(2), KC_RSFT
	),
	[1] = LAYOUT(
		KC_ESC, KC_GRV, KC_TAB, KC_NO, KC_NO, KC_NO, KC_NO, KC_NO, KC_MINS, KC_EQL,
		KC_1, KC_2, KC_3, KC_4, KC_5, KC_NO, KC_NO, KC_NO, KC_NO, KC_NO,
		KC_6, KC_7, KC_8, KC_9, KC_0, KC_NO, KC_LBRC, KC_RBRC, KC_SCLN, KC_QUOT, KC_NO,
		KC_NO, KC_NO, KC_NO, KC_NO, KC_NO, KC_LSFT, KC_LSFT, KC_NO, KC_NO, KC_NO, KC_NO, KC_NO
	),
	[2] = LAYOUT(
		KC_NO, KC_NO, KC_NO, KC_NO, KC_NO, KC_NO, KC_NO, KC_NO, KC_NO, KC_NO,
		KC_F1, KC_F2, KC_F3, KC_F4, KC_F5, KC_NO, KC_NO, KC_NO, KC_NO, KC_NO,
		KC_F6, KC_F7, KC_F8, KC_F9, KC_F10, KC_NO, KC_NO, KC_NO, KC_NO, KC_NO, KC_NO,
		KC_F11, KC_F12, KC_NO, KC_NO, KC_NO, KC_NO, KC_NO, KC_NO, KC_NO, KC_NO, EE_CLR, QK_BOOT
	),
	[3] = LAYOUT(
		KC_NO, KC_NO, KC_NO, KC_NO, KC_NO, KC_NO, KC_NO, KC_NO, KC_NO, KC_NO,
		KC_NO, KC_NO, KC_NO, KC_NO, KC_NO, KC_NO, KC_NO, KC_NO, KC_NO, KC_NO,
		KC_NO, KC_NO, KC_NO, KC_NO, KC_NO, KC_NO, KC_NO, KC_NO, KC_NO, KC_NO, KC_NO,
		KC_NO, KC_NO, KC_NO, KC_NO, KC_NO, KC_NO, KC_NO, KC_NO, KC_NO, KC_NO, KC_NO, KC_NO
	)
};

const uint16_t PROGMEM encoder_map[][NUM_ENCODERS][NUM_DIRECTIONS] = {
    [0] = { ENCODER_CCW_CW(KC_VOLD, KC_VOLU) },
    [1] = { ENCODER_CCW_CW(KC_VOLD, KC_VOLU) },
    [2] = { ENCODER_CCW_CW(KC_VOLD, KC_VOLU) },
    [3] = { ENCODER_CCW_CW(KC_VOLD, KC_VOLU) }
};

bool rgb_matrix_indicators_advanced_user(uint8_t led_min, uint8_t led_max) { 
  int is_layer = get_highest_layer(layer_state|default_layer_state);  
  HSV hsv = {0, 255, rgblight_get_val()};
  if (is_layer == 1) {
    hsv.h = 191; //PURPLE
  } else if (is_layer == 2)  {
    hsv.h = 85; //GREEN
  } else if (is_layer == 3)  {
    hsv.h = 43; //YELLOW
  } else {
    hsv.h = 128; //CYAN
  }
  RGB rgb = hsv_to_rgb(hsv);
  
  for (uint8_t i = led_min; i <= led_max -1; i++) {
      if (HAS_FLAGS(g_led_config.flags[i], 0x02)) {
        rgb_matrix_set_color(i, rgb.r, rgb.g, rgb.b);
      }
  }

  return false;
}  

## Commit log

2022-10-10 add: noraneko42c
    [noraneko42c.kicad_pcb, noraneko42c.kicad_sch]
2022-10-10 minor bugs fixs
    [noraneko42c.kicad_pcb]
2022-10-10 Add wired file from freerouting
2022-10-29 Update Noraneko42c Silk
    [noraneko42c.kicad_pcb]
2022-11-11 Update Noraneko52R
    [noraneko42c.kicad_pcb, noraneko42c.kicad_sch, noraneko52r.kicad_sch]
2022-11-14 Fix Noraneko52R LED Position
    [keymap.c]
2023-01-30 noraneko52r blackout ver.
    PCB&plate
    [noraneko52r-B_Cu.gbr, noraneko52r-B_Mask.gbr, noraneko52r-B_Silkscreen.gbr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]
2023-03-03 add: Noraneko52R v1.1
    [noraneko52r.kicad_sch]
2023-04-25 add: Noraneko42W PCB,Plate
    [noraneko42w.kicad_sch]
2023-05-05 add: Noraneko42L
    [noraneko42l.kicad_sch, noraneko42w.kicad_sch]
2023-09-25 add: Noraneko42C v2 PCB/Plate
    [noraneko42c.kicad_sch]
2023-10-27 add: noraneko42gr
    [noraneko42gr.kicad_sch]
2023-11-09 fix: led settings
2023-11-11 add: noraneko42gr v1.1
    [noraneko42gr.kicad_sch]
2024-02-24 add: 42gr v1.2 and 42a pcb
    [noraneko42a.kicad_sch, noraneko42gr.kicad_sch]
2024-06-01 add: noraneko42w v1.1
    [noraneko42w.kicad_sch]
2024-08-26 add: 42c v2.1 pcb
    [noraneko42c.kicad_sch]
2024-08-26 add: 42sgr
    [noraneko42sgr.kicad_sch]
2024-11-24 Update noraneko42uzu config.h, keyboard.json, keymap.c, and 28 more files
    [noraneko42uzu.kicad_sch]
2025-02-12 add: Noraneko42O
    [noraneko42o.kicad_sch]
2025-03-14 Update noraneko43ts.zip, noraneko43ts_vial.uf2, 1N4148W.kicad_mod, and 22 more files
    [noraneko43ts.kicad_sch]
2026-08-19 Remove ~noraneko42c.kicad_pcb.lck, ~noraneko42c.kicad_pro.lck, and ~noraneko42c.kicad_sch.lck
2026-08-19 add: Noraneko42C stl files
